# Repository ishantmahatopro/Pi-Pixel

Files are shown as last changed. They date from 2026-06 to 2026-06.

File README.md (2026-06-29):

# PI-Pixel

PI-Pixel is my Raspberry Pi Zero 2 W camera build. It is built like a tiny Linux camera instead of a locked-down gadget, so the firmware runs as a normal Python script on boot, saves photos to the SD card, and keeps the whole thing easy to hack on.

## What's inside

- Raspberry Pi Zero 2 W running the firmware
- Raspberry Pi Camera Module 3 on the CSI ribbon
- ILI9341 2.8" SPI display wiring in the build notes
- WS2812B status LED support in the wiring notes
- 2S battery pack, charger board, and buck converter for power

---
### Onshape [Link](https://cad.onshape.com/documents/13b8fbce3765921378175305/w/f4802430950fd62b1acb4392/e/c97a4828b4a17766dba064f5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)
---

## Wiring

Wiring

## Gallery

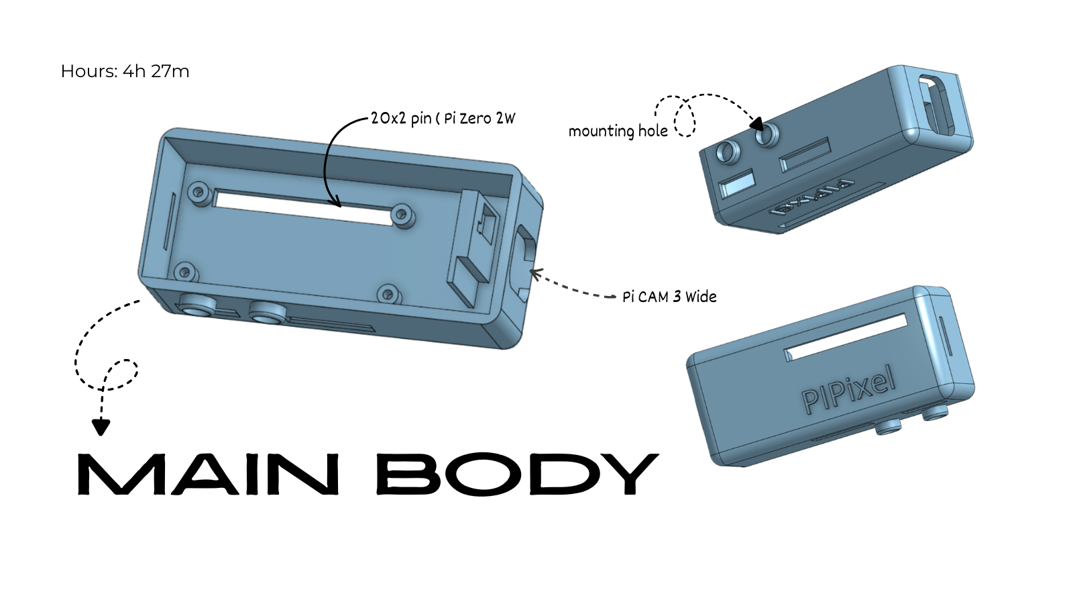
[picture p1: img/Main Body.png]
Main body


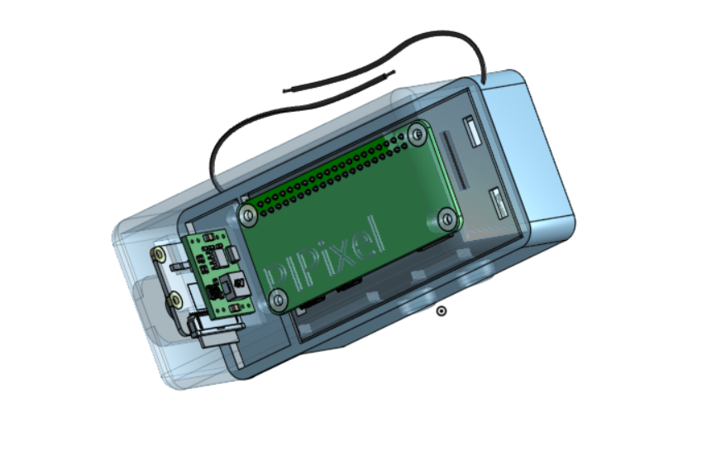
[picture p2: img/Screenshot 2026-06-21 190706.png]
Assembly view


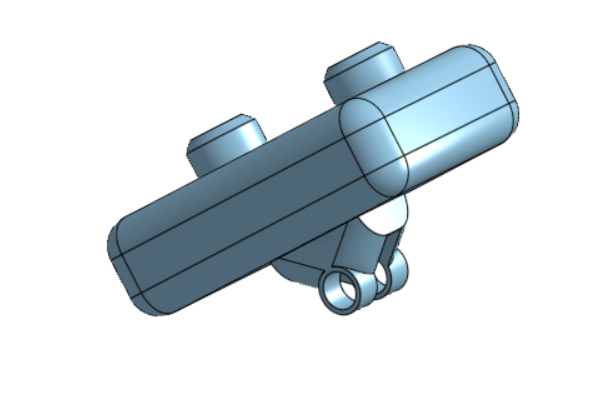
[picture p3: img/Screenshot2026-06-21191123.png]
Mounting plate


## Quick setup

1. Wire the shutter button to BCM 17 and GND.
2. Install the dependencies on the Pi.

```bash
sudo apt update
sudo apt install -y python3-gpiozero rpicam-apps
```

If your image still uses the older camera package, install `libcamera-apps` instead of `rpicam-apps`.

3. Copy the firmware to the Pi and run it.

```bash
python3 firmware/pipixel.py
```

4. To make it start on boot, use the systemd service example in [firmware.md](firmware.md).

## How it works

The firmware waits for the shutter button, captures a photo with `rpicam-still` or `libcamera-still`, and saves it with a timestamped filename under `~/Pictures/PI-Pixel/`.

The bigger project notes in [JOURNAL.md](JOURNAL.md) cover the wiring, power chain, and the rest of the build process in the same tone I've been writing it in.

## Firmware

Full setup notes, boot service instructions, and troubleshooting are in [firmware.md](firmware.md).

## Build notes

- The camera button is wired as a pull-up input, so it triggers when connected to ground.
- The display and LED wiring are in the journal for the full hardware layout.
- The project is meant to be easy to tweak, so the firmware stays small and readable on purpose.

## BOM.csv

| Name | Purpose | Quantity | Total Cost (USD) | Link | Distributor |
| --- | --- | ---: | ---: | --- | --- |
| 3D printing | 3D case | 2 | 10.00 |  | Robu |
| Raspberry Pi Zero 2W  | Motherboard | 1 | 30.50 | https://robu.in/product/raspberry-pi-zero-2-w-with-header/ | Robu |
| Samsung 18560 2500mah Li ion Battery | Battery | 2 | 12.00 | https://robu.in/product/samsung-inr18650-25r-2500mah-li-ion-battery/ | Robu |
| WS2812B (Pack of 10) | Status Leds | 1 | 2.00 | https://robu.in/product/ws2812b-rgb-addressable-led-module/ | Robu |
| 2s 8.4v 4a-18650 lithium-battery-charger module type-c | Battery Charging Module  | 1 | 1.50 | https://robu.in/product/2s-8-4v-4a-18650-lithium-battery-charger-module-type-c/ | Robu |
| Battery Holder | Battery Holder | 1 | 1.00 | https://robu.in/product/2-x-18650-blm-cell-box-with-wire-without-cover/ | Robu |
| MP1584 dc dc adjustable buck module 3a | Buck Convertor | 1 | 1.00 | https://robu.in/product/mini-mp1584-dc-dc-adjustable-buck-module-3a/ | Robu |
| Pi CAM 3 Wide | Camera | 1 | 40.40 | https://robu.in/product/raspberry-pi-camera-module-3-wide/ | Robu |

Total cost: $98.40

## License

See [LICENSE](LICENSE).

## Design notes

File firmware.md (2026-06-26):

# Firmware

This is the firmware guide for PI-Pixel. The goal is simple: boot the Pi, wait for the shutter button, capture a frame, and save it with a clean timestamped filename.

## Current firmware

The active script lives in [firmware/pipixel.py](firmware/pipixel.py).

What it does:

- Creates the save folder under `~/Pictures/PI-Pixel/`
- Waits for the shutter button on BCM 17
- Captures a still image with `rpicam-still` or `libcamera-still`
- Saves files as `IMG_YYYYMMDD_HHMMSS.jpg`

## Dependencies

Install the Python and camera packages on Raspberry Pi OS:

```bash
sudo apt update
sudo apt install -y python3-gpiozero rpicam-apps
```

If your image does not have `rpicam-apps`, use `libcamera-apps` instead.

## Wiring used by the firmware

- Shutter button: BCM 17 to GND
- Button mode: pull-up input

The wider hardware notes in [JOURNAL.md](JOURNAL.md) include the display, LED, power, and camera wiring used for the full build.

## Run manually

From the repository root on the Pi:

```bash
python3 firmware/pipixel.py
```

If the camera command is missing, install the camera app package first and try again.

## Run on boot with systemd

Create the service file:

```bash
sudo nano /etc/systemd/system/pi-pixel.service
```

Paste this:

```ini
[Unit]
Description=PI-Pixel Camera Firmware
After=multi-user.target

[Service]
Type=simple
WorkingDirectory=/home/pi/PI-Pixel
ExecStart=/usr/bin/python3 /home/pi/PI-Pixel/firmware/pipixel.py
Restart=on-failure
RestartSec=3
User=pi

[Install]
WantedBy=multi-user.target
```

Then enable it:

```bash
sudo systemctl daemon-reload
sudo systemctl enable pi-pixel.service
sudo systemctl start pi-pixel.service
```

To check logs:

```bash
sudo journalctl -u pi-pixel.service -f -n 50
```

## Troubleshooting

- No photos saved: check the save folder exists and the Pi user can write to `~/Pictures/PI-Pixel/`.
- Camera command not found: install `rpicam-apps` or `libcamera-apps`.
- Button does nothing: confirm BCM 17 is wired to the switch and the other side goes to GND.

## Notes

The firmware is intentionally lean. The display and extra peripherals are documented in the journal, but the capture loop stays focused on the shutter path so it boots clean and is easy to debug.

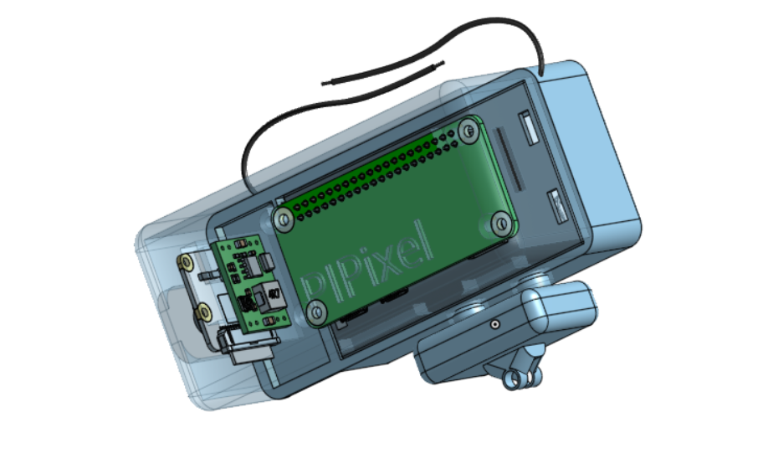
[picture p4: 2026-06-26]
img/Screenshot 2026-06-21 191345.png

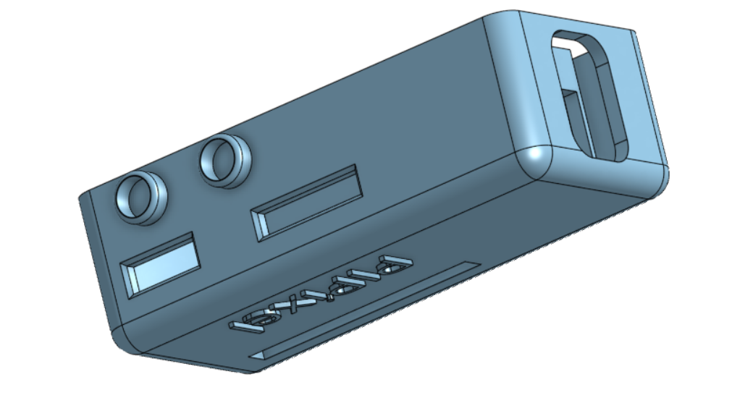
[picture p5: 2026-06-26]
img/Screenshot 2026-06-21 183837.png

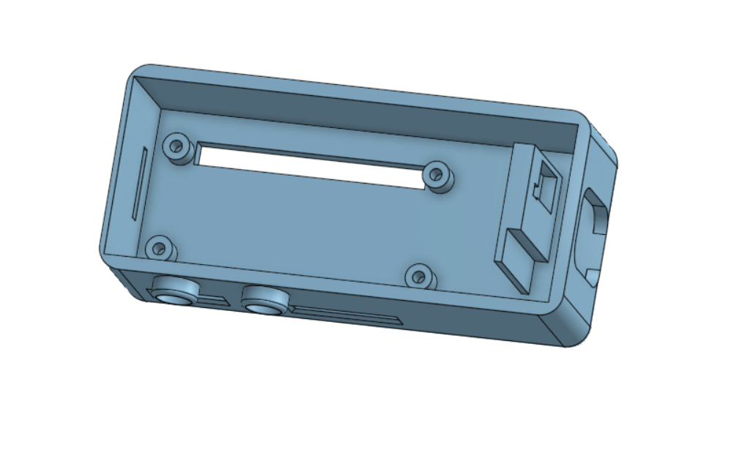
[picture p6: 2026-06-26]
img/Screenshot 2026-06-21 183451.png

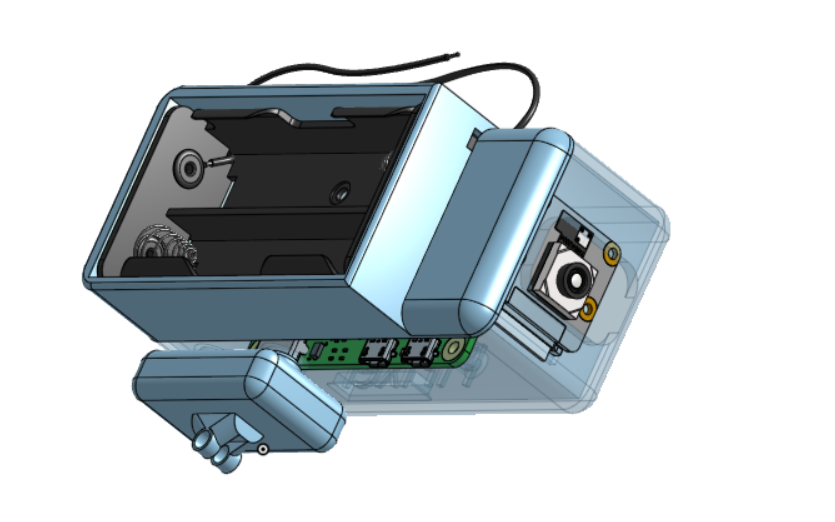
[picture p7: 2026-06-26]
img/Screenshot 2026-06-21 191639.png

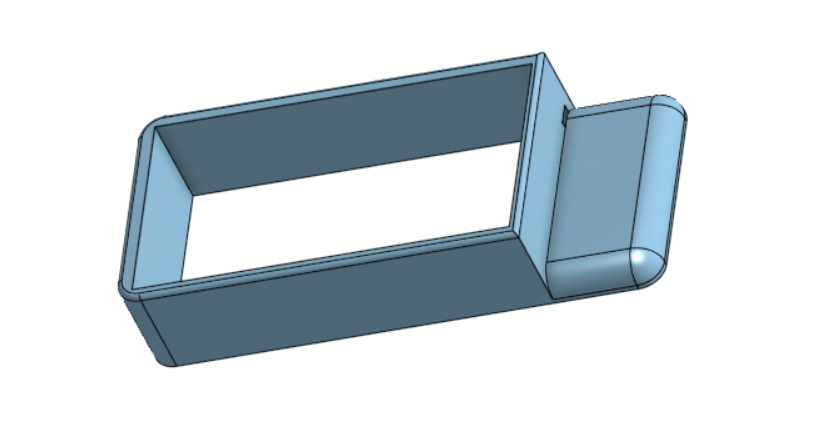
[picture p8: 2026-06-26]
img/Screenshot 2026-06-21 185239.png

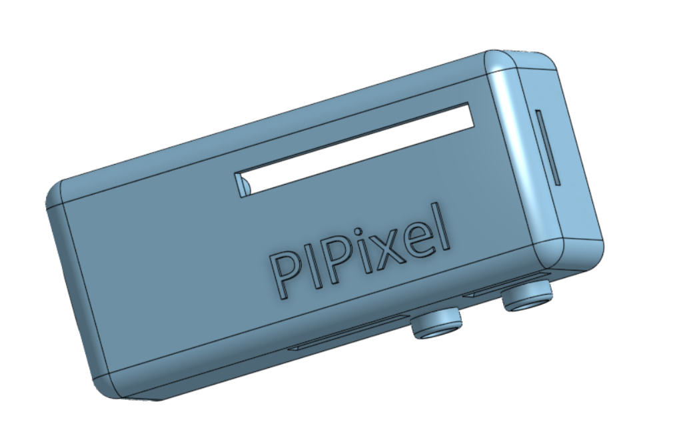
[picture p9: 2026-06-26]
img/Screenshot 2026-06-21 183940.png

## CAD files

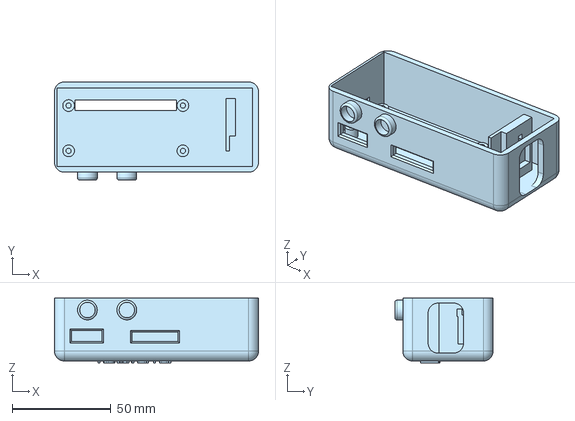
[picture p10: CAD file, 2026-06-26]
CAD/Main Case.step
103.5 x 49.9 x 32.9 mm

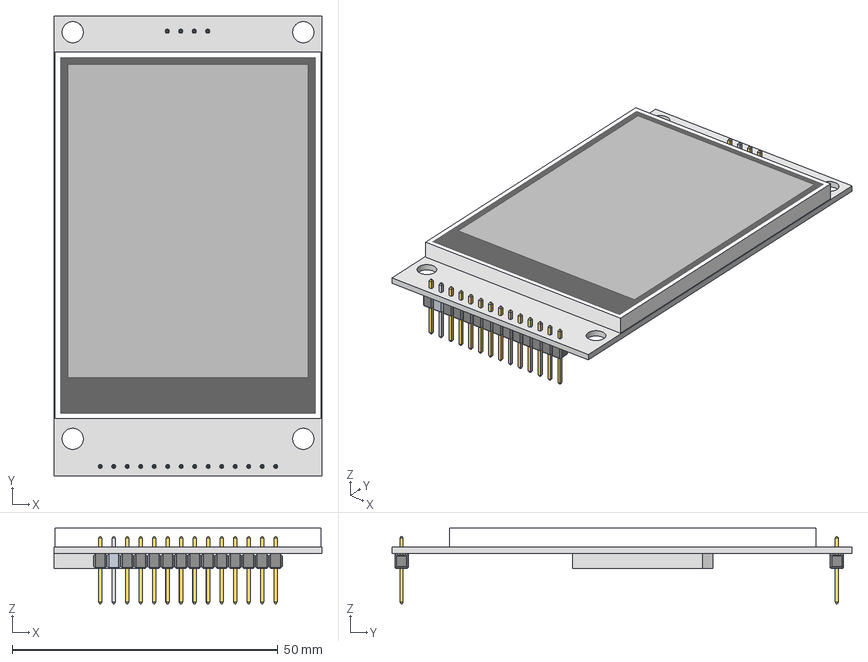
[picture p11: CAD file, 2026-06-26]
CAD/ILI9341_28.stp
50.4 x 86.6 x 14.2 mm
ILI9341_28_layer
SDcard
EDGE
EDGE_1
EDGE_2
EDGE_3
EDGE_4
EDGE_5
EDGE_6
=_[0_1_1_12]
=_[0_1_1_13]
=_[0_1_1_14]
=_[0_1_1_15]
=_[0_1_1_17]
=_[0_1_1_18]
=_[0_1_1_19]
=_[0_1_1_20]
EDGE_7
EDGE_8
EDGE_9
EDGE_10
EDGE_11
EDGE_12
EDGE_13
=_[0_1_1_12]_1
=_[0_1_1_13]_1
=_[0_1_1_14]_1
=_[0_1_1_15]_1
=_[0_1_1_16]
=_[0_1_1_17]_1
=_[0_1_1_18]_1
=_[0_1_1_19]_1
=_[0_1_1_20]_1
=_[0_1_1_21]
=_[0_1_1_22]
=_[0_1_1_23]
=_[0_1_1_24]
=_[0_1_1_25]
=_[0_1_1_27]
=_[0_1_1_28]
=_[0_1_1_29]
=_[0_1_1_30]
=_[0_1_1_31]
=_[0_1_1_32]
=_[0_1_1_33]
=_[0_1_1_34]
=_[0_1_1_35]
=_[0_1_1_36]
=_[0_1_1_37]
=_[0_1_1_38]
=_[0_1_1_39]
=_[0_1_1_40]

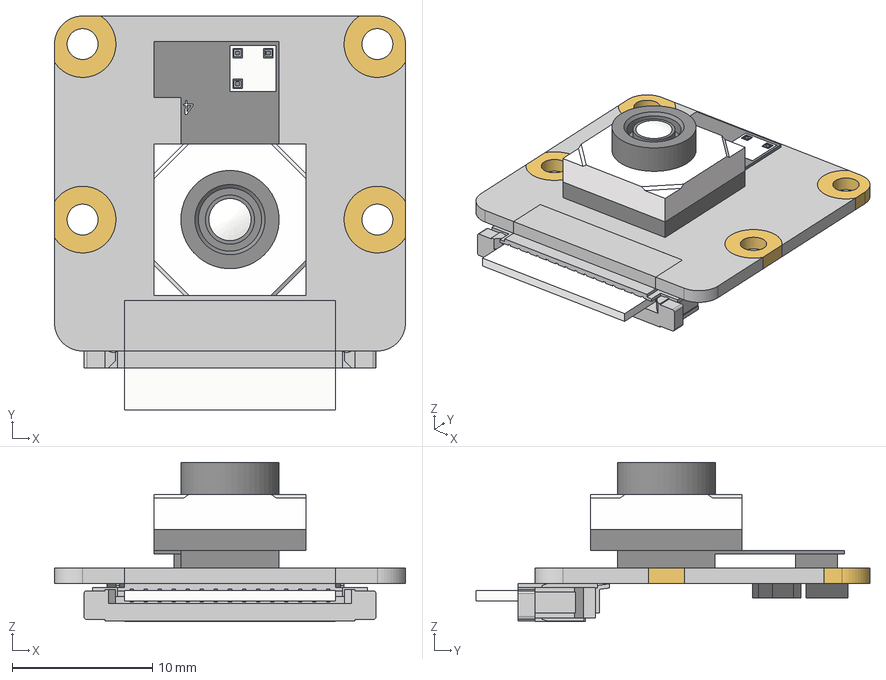
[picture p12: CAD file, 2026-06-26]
CAD/Camera Moudule 3.step
25.0 x 28.1 x 11.3 mm
Board
sfw15r3ste1lf
Sensor
Lens
Ring
Mount
Housing

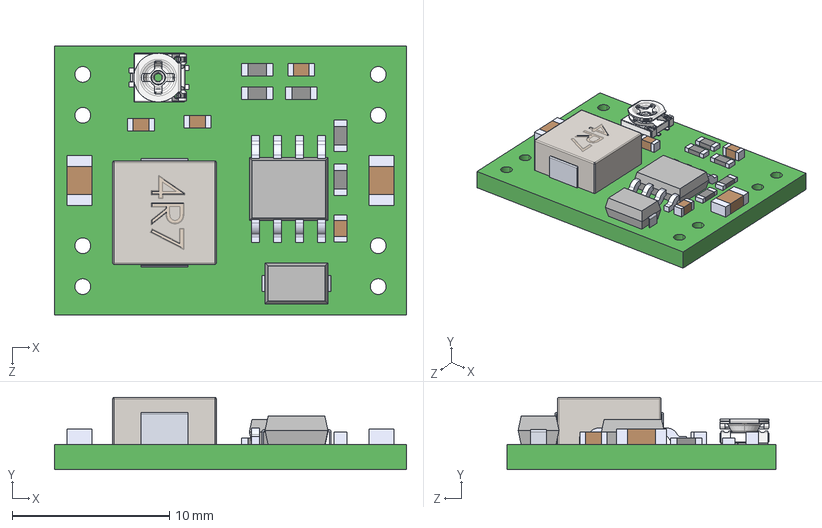
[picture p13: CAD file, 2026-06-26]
CAD/DCMP1584EN Step Down Buck Converter.STEP
22.4 x 4.60 x 17.1 mm
PCB, DC-DC 4.5-28V to 0.8-20V Output 3A MP1584EN Step Down Buck Converter
MP1584EN CHIP, DC-DC 4.5-28V to 0.8-20V Output 3A MP1584EN Step Down Buck Converter
INDUCTOR, DC-DC 4.5-28V to 0.8-20V Output 3A MP1584EN Step Down Buck Converter
SCHOTTKY DIODE, DC-DC 4.5-28V to 0.8-20V Output 3A MP1584EN Step Down Buck Converter
LARGE SMD CAPACITOR, DC-DC 4.5-28V to 0.8-20V Output 3A MP1584EN Step Down Buck Converter x 2
SMD RESISTOR, 104, DC-DC 4.5-28V to 0.8-20V Output 3A MP1584EN Step Down Buck Converter x 4
SMD RESISTOR, 822, DC-DC 4.5-28V to 0.8-20V Output 3A MP1584EN Step Down Buck Converter
SMALL SMD CAPACITOR, DC-DC 4.5-28V to 0.8-20V Output 3A MP1584EN Step Down Buck Converter x 4
POTENTIOMETER, DC-DC 4.5-28V to 0.8-20V Output 3A MP1584EN Step Down Buck Converter

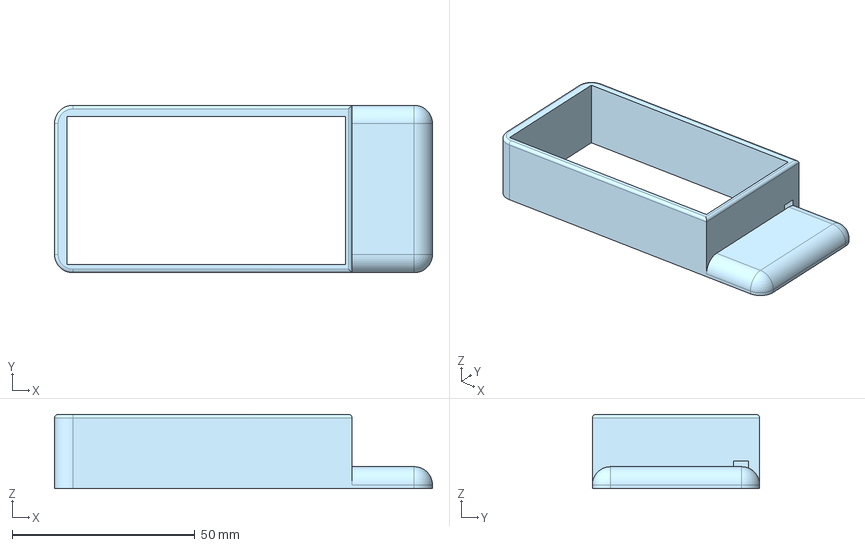
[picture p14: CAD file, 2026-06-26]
CAD/Top Case.step
103.5 x 45.9 x 20.3 mm

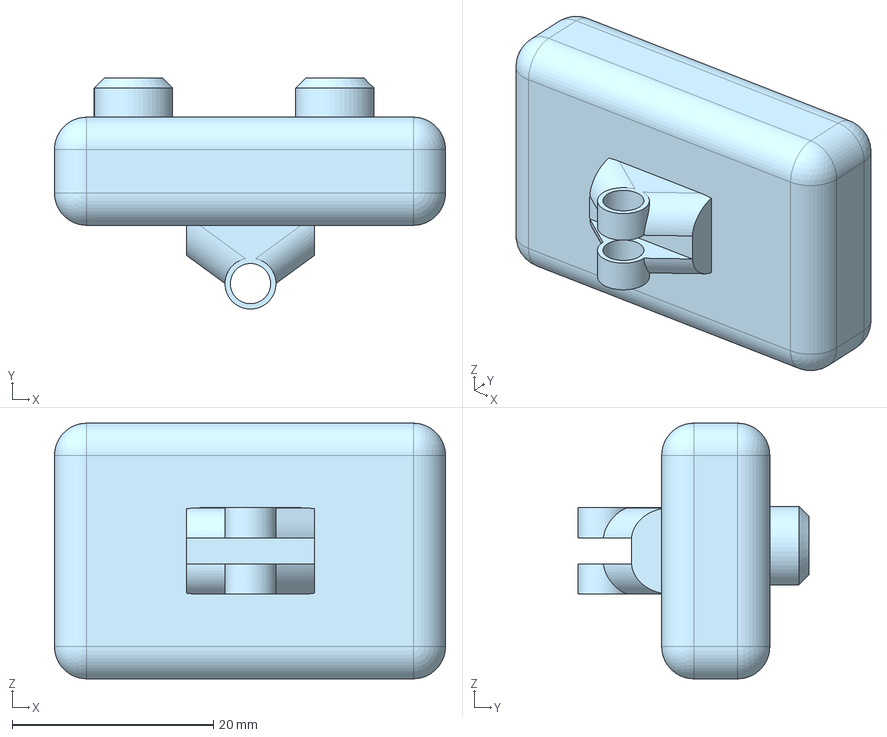
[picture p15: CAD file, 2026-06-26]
CAD/Mounting Plate.step
38.8 x 23.0 x 25.4 mm

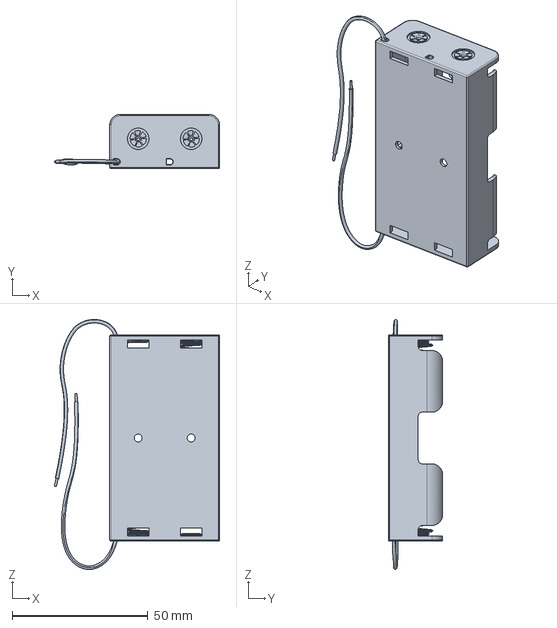
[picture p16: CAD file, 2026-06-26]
CAD/18650 Battery Holder 2x v1.step
60.9 x 20.0 x 92.0 mm

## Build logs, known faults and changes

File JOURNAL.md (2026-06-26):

<!--
  This journal is auto generated by Stasis.
-->

# 6/26/2026 2 PM - Firmware

_Time spent: 1.25h_

# Raspberry Pi Firmware Development

I have begun developing the firmware for the project using a Raspberry Pi Zero W. Although this is my first time working with this specific microcomputer, the development process is highly efficient because the Pi runs a full Linux-based operating system. This eliminates the need for complex micro-controller flashing; instead, the logic can be implemented directly by writing a Python script and configuring it to execute automatically on boot.

Currently, the GPIO (General Purpose Input/Output) pins have been assigned placeholder values in the code, as the final hardware layout and pin configurations are yet to be finalized.

The core functional requirements of the Python script are as follows:

* **Initialize System:** Display a boot-up splash screen on the interface.
* **Interrupt Handling / Input Sensing:** Wait for a hardware trigger via a shutter button press.
* **Data Acquisition:** Capture an image using the connected camera module.
* **File Management:** Save the captured image to the SD card, utilizing a timestamp-based naming convention for unique file identification.

## Implementation Code

```python
import os
import time
from datetime import datetime
import subprocess
from gpiozero import Button
from PIL import Image, ImageDraw, ImageFont

# --- CONFIGURATION ---
SHUTTER_BUTTON_PIN = 17  # BCM pin 17 (Physical pin 11)
SAVE_DIRECTORY = "/home/pi/Pictures/"

# Ensure the save directory exists
os.makedirs(SAVE_DIRECTORY, exist_ok=True)

# --- DISPLAY FUNCTIONS ---
def show_splash_screen():
    print("Initializing Camera System...")
    # If using an OLED/LCD shield, insert your display library initialization here.
    # For now, this acts as a placeholder or outputs to a connected SPI/I2C screen.
    try:
        # Example using Pillow to create a splash image canvas
        img = Image.new("1", (128, 64), color=0)
        draw = ImageDraw.Draw(img)
        draw.text((10, 20), "CAMERA READY", fill=1)
        # img.show() # Uncomment if testing on a desktop environment
    except Exception as e:
        print(f"Display error: {e}")

def show_capture_feedback():
    print("Capturing photo...")
    # Add temporary screen change here (e.g., "SAVING...")

# --- CAMERA FUNCTION ---
def capture_image():
    show_capture_feedback()
    
    # Generate a unique timestamped filename
    timestamp = datetime.now().strftime("%Y%m%d_%H%M%S")
    filename = f"{SAVE_DIRECTORY}IMG_{timestamp}.jpg"
    
    # Using libcamera-still via a system call (Standard for Raspberry Pi OS Bookworm)
    try:
        # --immediate skips the preview window delay for a faster shutter response
        subprocess.run(["libcamera-still", "-o", filename, "--immediate"], check=True)
        print(f"Image successfully saved to {filename}")
    except subprocess.CalledProcessError as e:
        print(f"Camera capture failed: {e}")
    
    # Return to ready state on display
    show_splash_screen()

# --- MAIN EXECUTION ---
def main():
    show_splash_screen()
    
    # Initialize the button. 
    # pull_up=True means the pin is held HIGH by default; 
    # the button should connect this pin to GND when pressed (LOW).
    shutter_button = Button(SHUTTER_BUTTON_PIN, pull_up=True)
    
    print("Waiting for shutter press... Press Ctrl+C to exit.")
    
    # Assign the capture function to trigger when the button is pressed
    shutter_button.when_pressed = capture_image

    # Keep the script running in the background
    while True:
        time.sleep(1)

if __name__ == "__main__":
    main()

```

```

```





# 6/26/2026 1 PM - Notes

_Time spent: 1h_

So how does it work ? 

Well now that it runs from a fat cell ? 2S 18560 Li ion battery that to 2500mah using the universal formula and math my calc comes to around 3.2 hrs of battery backup which is at 100% efficienncy which is not possible or is it realistic....

After a real life condition and usage it would range between 2-2.5 hrs of usage...

And for those who are asking how it works and where is the display ?
Well, The camera feed goes to Pi Zero 2W which the main motherboard that runs a Lite OS + Records / Streams + saves the footage all at the same time... and this would cause a general problem of heat ++++ for that we are going to be using heatsinks for the Pi zero... and some natural air flow..... and then an esp32 c6 will be connected to the Pi Zero 2w using UART for controlling the camera wirelessly from your phone or any internet connect devices.... 

Basically the ESP32 will the send commands to the Pi via UART and then the Pi will perform those actions....

And as per where the hell is the display ???
For those who wanna add a display i have given the pin connections... for connecting the SPI display... 

As for me... I found out I could just stream the footage over via wifi to my server and record it using  vlc... so no issues there... also since i am using it as CCTV so i dont need a display lamo... but there is space to add one i guess...





# 6/26/2026 1 PM - CAD: Part 3

_Time spent: 3.15h_

after designing part 1 and 2, I assembled them on Onshape, and placed the Components, after a few adjustments, I got a rather un aesthetic shape, but this was my first time so yea... (not cadding but designing a cctv ) and the overall look was kinda okayish... and after a feedback from my friends, I concluded its polished enough for tier 3 and that i had to now check for a mounting plate to attach to my cam stand....



After measuring the dock with my trusty scale, I cadded the Mounting plate using the two holes as a tight support to hold the weight of the camera, and a mount on the other side, so that i can tilt the cam at a certain angle.



Final Design



Now I just need to upload all these files to github have a structised foldeer and place all the required files + journal + readme + bom i guess ? :) lamo





# 6/26/2026 1 PM - CAD: Part 2

_Time spent: 1.05h_

After a short break, I started desiging the part 2. So this holds the 2S 18560 cell battery's. Find the CAD for the holder was quite easy compared to the other parts :/ But GrabCAD is always there !!!

Yea, Once the part 2 was done I had figure the way of attaching to part 1: Main Case.... and i went with super glue... cuz i am lazy to design a lock or some kind to attachment plug... and that my laptop is barely able to render these designs... : (





# 6/26/2026 1 PM - CAD: Part 1

_Time spent: 4.45h_

I began by finding and downloading 3D models of all the components I would be using. This process took a significant amount of time, as I had to search extensively to locate every part! After that, I started designing the case in Onspahe on my laptop. I first created a rectangular base for the body. Next, I added a square hole in the back center for the mount. The challenging part was designing the body... Cuz it had to ergonomic yet spacious for air venting... as Pi Zero needs active air flow for the passive heatsinks....

Because of the size I had to make two holes for stable mounting.... I first intended to add a display but because of the design, I removed it and converted in a CCTV / Cinematic camera / Remote Camera / Spotting camera...

Images: 
Main Body












# 6/26/2026 7 AM - Wiring Details

_Time spent: 0.6h_

### **Raspi Cam 3**

* **CAM1** is connected to the Raspberry Pi Zero 2W.

### **Mini MP1584EN DC-DC Buck Converter**

* **IN \-** is connected to the GND of the 2S 2A TYPE C CHARGING MODULE.  
* **IN \+** is connected to the VIN of the 2S 2A TYPE C CHARGING MODULE.  
* **OUT \+** is connected to the 5V pin of the Raspberry Pi Zero 2W and the VCC of the ILI9341 Touch 2.8".  
* **OUT \-** is connected to the GND of the ILI9341 Touch 2.8" and the Ground of the Raspberry Pi Zero 2W.

### **2S 2A TYPE C CHARGING MODULE**

* **BAT \+** is connected to the \+ of the 18650 Holder 2P.  
* **GND** is connected to the \- of the 18650 Holder 2P and the IN \- of the Mini MP1584EN DC-DC Buck Converter.  
* **VIN** is connected to the IN \+ of the Mini MP1584EN DC-DC Buck Converter.

### **18650 Holder 2P**

* **\+** is connected to the BAT \+ of the 2S 2A TYPE C CHARGING MODULE.  
* **\-** is connected to the GND of the 2S 2A TYPE C CHARGING MODULE.

### **Raspberry Pi Zero 2W**

* **5V** is connected to the OUT \+ of the Mini MP1584EN DC-DC Buck Converter and the \+5V of the WS2812B LED.  
* **Ground** is connected to the OUT \- of the Mini MP1584EN DC-DC Buck Converter and the GND of the WS2812B LED.  
* **GPIO 10 MOSI** is connected to the SDI(MOSI) of the ILI9341 Touch 2.8".  
* **GPIO 9 MOSI** is connected to the SDO(MISO) of the ILI9341 Touch 2.8".  
* **GPIO 11 SCLK** is connected to the SCK of the ILI9341 Touch 2.8".  
* **GPIO 13(PWM)** is connected to the LED of the ILI9341 Touch 2.8".  
* **GPIO 25** is connected to the D/C of the ILI9341 Touch 2.8".  
* **GPIO 24** is connected to the RESET of the ILI9341 Touch 2.8".  
* **GPIO 19** is connected to the CS of the ILI9341 Touch 2.8".  
* **GPIO 18** is connected to the Din of the WS2812B LED.

### **ILI9341 Touch 2.8"**

* **GND** is connected to the OUT \- of the Mini MP1584EN DC-DC Buck Converter.  
* **VCC** is connected to the OUT \+ of the Mini MP1584EN DC-DC Buck Converter.  
* **SDI(MOSI)** is connected to the GPIO 10 MOSI of the Raspberry Pi Zero 2W.  
* **SDO(MISO)** is connected to the GPIO 9 MOSI of the Raspberry Pi Zero 2W.  
* **SCK** is connected to the GPIO 11 SCLK of the Raspberry Pi Zero 2W.  
* **LED** is connected to the GPIO 13(PWM) of the Raspberry Pi Zero 2W.  
* **D/C** is connected to the GPIO 25 of the Raspberry Pi Zero 2W.  
* **RESET** is connected to the GPIO 24 of the Raspberry Pi Zero 2W.  
* **CS** is connected to the GPIO 19 of the Raspberry Pi Zero 2W.

### **WS2812B LED**

* **GND** is connected to the Ground of the Raspberry Pi Zero 2W.  
* **\+5V** is connected to the 5V of the Raspberry Pi Zero 2W.  
* **Din** is connected to the GPIO 18 of the Raspberry Pi Zero 2W.

`NOTE: These connection are AI generated. But has been verified by the author 
~ Shlok :)`





# 6/26/2026 7 AM - Tinkering and Drawing the Schematic

_Time spent: 3.616666666666667h_

Alright, so I’m finally starting this project for Stasis! I'm officially calling it the PiPixel. The absolute dream is to build a pocket-sized, retro-looking digital camera (kind of like an old Sony Cyber-shot style layout). I want a custom 3D-printed case, a display screen on the back so I can scroll through my photos and check out what I shot.

Spent hours today just comparing camera sensors. I almost went with a cheaper one, but ended up choosing the Raspi Cam 3 because it actually has autofocus, which is a total lifesaver. For the main board, I’m using the Pi Zero 2W. Honestly, it’s the absolute bare minimum that can handle a live camera stream without turning into a total slideshow, but it’s tiny and perfect for this form factor.

Power delivery was a whole rabbit hole. I initially wanted to use a super thin 1500mAh LiPo battery paired with a TP4056 charger and an MT3608 boost converter to get a steady 5V. But i had to change to using 2S Standard 18650 battery  2500mah Cuz I had power the Pi, TFT LCD, CAM and RGBA leds for a min 2hrs. For the screen, I’m using an ILI9341 Non Touch 2.8" display, and I've got a ESP32 which i will be using for Remote Control. I’m also adding a WS2812B RGB LED for status indications. I’m deliberately avoiding a custom PCB because I want to be flexible with where I stuff the components inside the case.

Schematic Diagram: -




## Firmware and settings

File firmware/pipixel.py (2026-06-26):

from __future__ import annotations

import shutil
import subprocess
import time
from datetime import datetime
from pathlib import Path

from gpiozero import Button

SHUTTER_BUTTON_PIN = 17  # BCM pin 17, physical pin 11
SAVE_DIRECTORY = Path.home() / "Pictures" / "PI-Pixel"
CAMERA_COMMANDS = ("rpicam-still", "libcamera-still")
CAPTURE_FLAGS = ("--immediate", "--nopreview")

is_capturing = False


def ensure_save_directory() -> None:
    SAVE_DIRECTORY.mkdir(parents=True, exist_ok=True)


def get_camera_command() -> str:
    for command in CAMERA_COMMANDS:
        if shutil.which(command):
            return command
    raise RuntimeError("No camera command found. Install rpicam-apps or libcamera-apps.")


def show_splash_screen() -> None:
    print("Camera ready. Press the shutter button to take a shot.")


def show_capture_feedback() -> None:
    print("Capturing photo...")


def capture_image() -> None:
    global is_capturing

    if is_capturing:
        return

    is_capturing = True
    try:
        show_capture_feedback()
        timestamp = datetime.now().strftime("%Y%m%d_%H%M%S")
        filename = SAVE_DIRECTORY / f"IMG_{timestamp}.jpg"
        command = [get_camera_command(), "-o", str(filename), *CAPTURE_FLAGS]

        subprocess.run(command, check=True)
        print(f"Image saved to {filename}")
    except (RuntimeError, subprocess.CalledProcessError) as error:
        print(f"Camera capture failed: {error}")
    finally:
        is_capturing = False
        show_splash_screen()


def main() -> None:
    ensure_save_directory()
    show_splash_screen()

    shutter_button = Button(SHUTTER_BUTTON_PIN, pull_up=True, bounce_time=0.1)
    shutter_button.when_pressed = capture_image

    print("Waiting for shutter press... Press Ctrl+C to exit.")

    try:
        while True:
            time.sleep(1)
    except KeyboardInterrupt:
        print("Shutting down cleanly.")


if __name__ == "__main__":
    main()

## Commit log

2026-06-26 Added neccessary files
    [BOM.csv]
2026-06-29 Added Wiring
